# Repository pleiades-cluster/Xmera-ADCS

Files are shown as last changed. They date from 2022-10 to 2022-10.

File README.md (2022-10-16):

# Xmera-ADCS
The Official ADCS Design on PROVES Xmera
# ADCS_V1
This was the first version of the ADCS board developed by Rachel Sarmiento and Nicole Maggard. This board was uploaded on 10/12/2022 and is the most relevant and up to date version. This board utilizes a raspberry pi zero for calculations and control. This board includes an embedded Magnetorquer in the inner layers. Parts utilized on V1 include: STSPIN250 (Motor Drivers), PCA9548A (I2C Multiplexer), LIS331LH (6D Orientation IMUs), and LIS3MDL (Magnetometers).

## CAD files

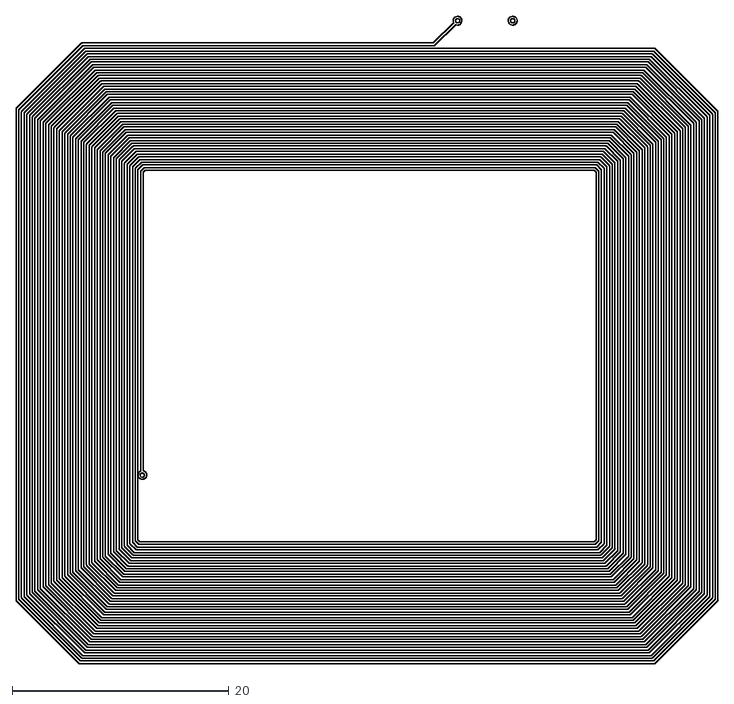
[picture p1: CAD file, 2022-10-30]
ADCS_V1/V0 Coil-In2_Cu.dxf
64.8 x 59.7

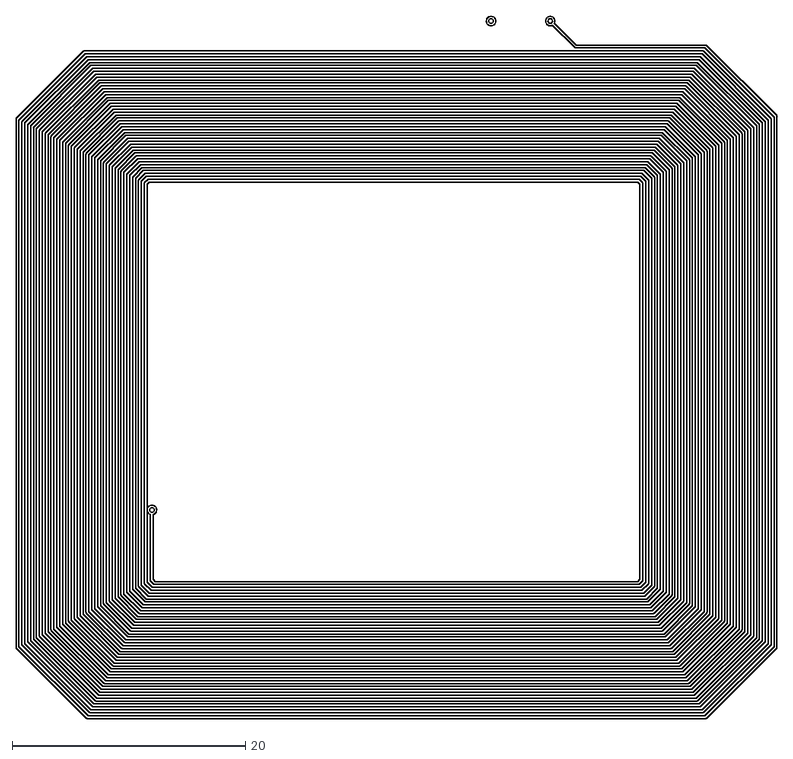
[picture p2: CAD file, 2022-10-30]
ADCS_V1/V0 Coil-In1_Cu.dxf
65.3 x 60.2

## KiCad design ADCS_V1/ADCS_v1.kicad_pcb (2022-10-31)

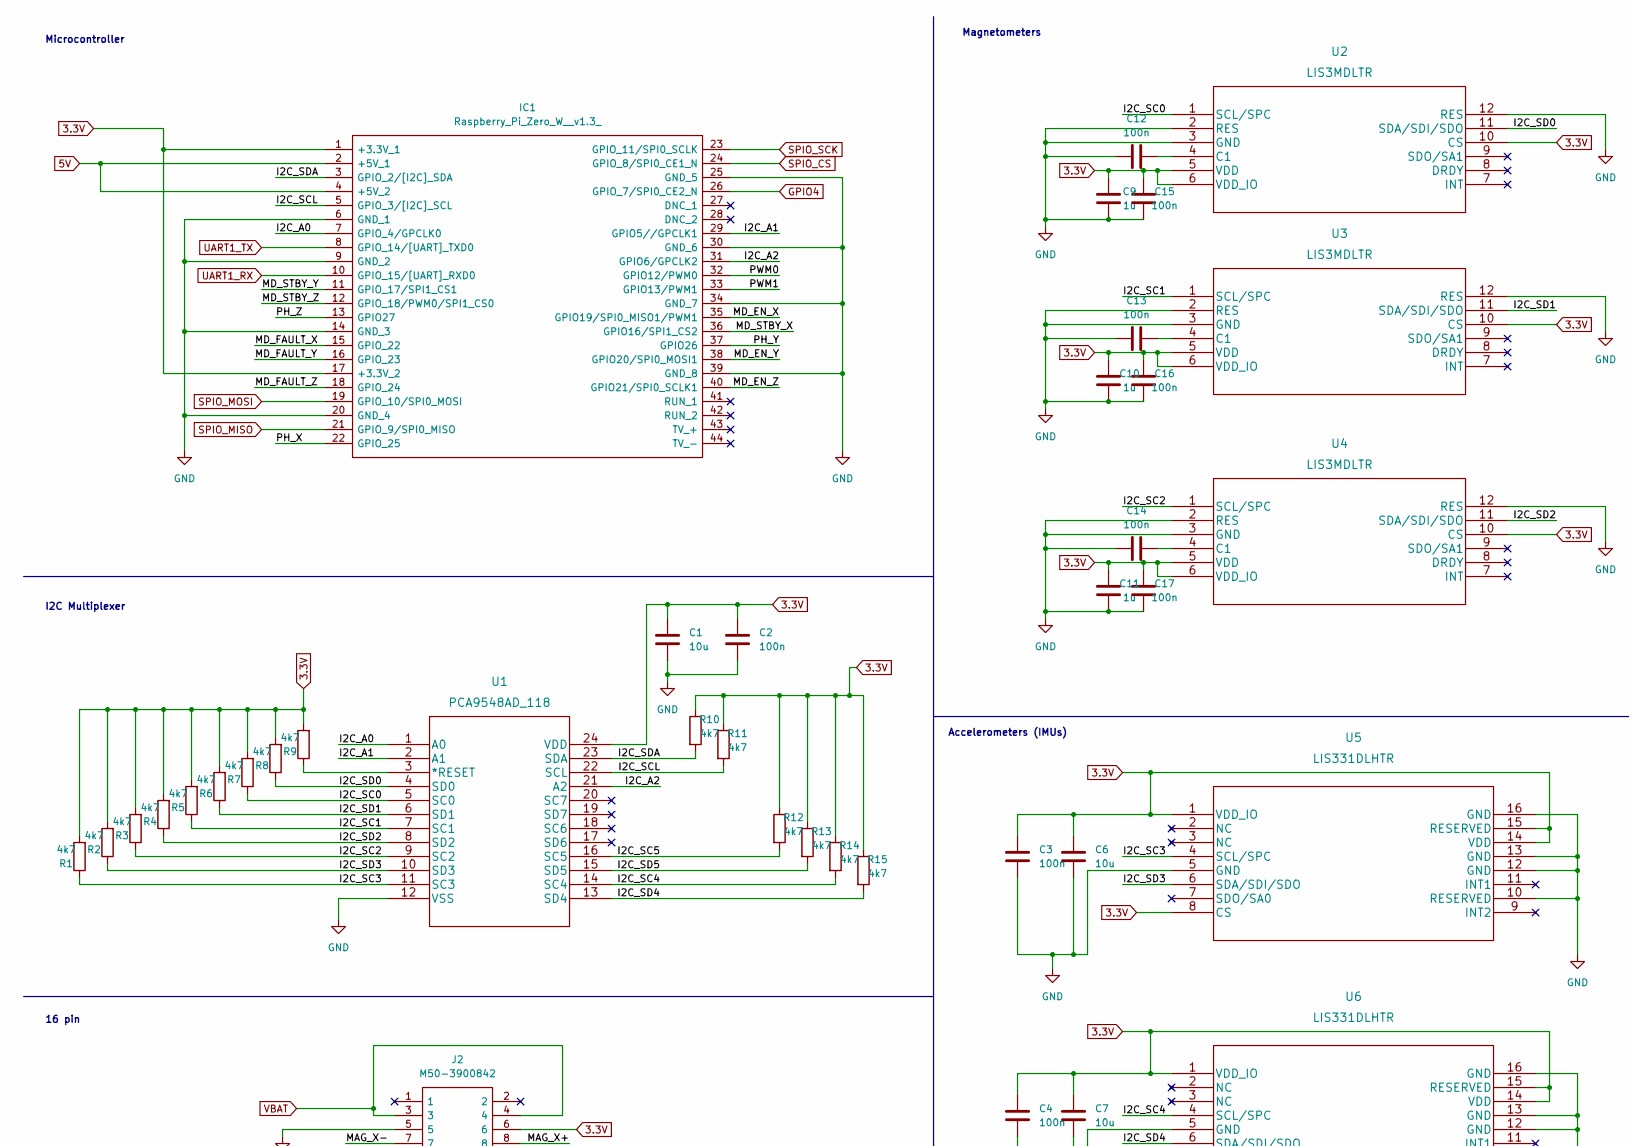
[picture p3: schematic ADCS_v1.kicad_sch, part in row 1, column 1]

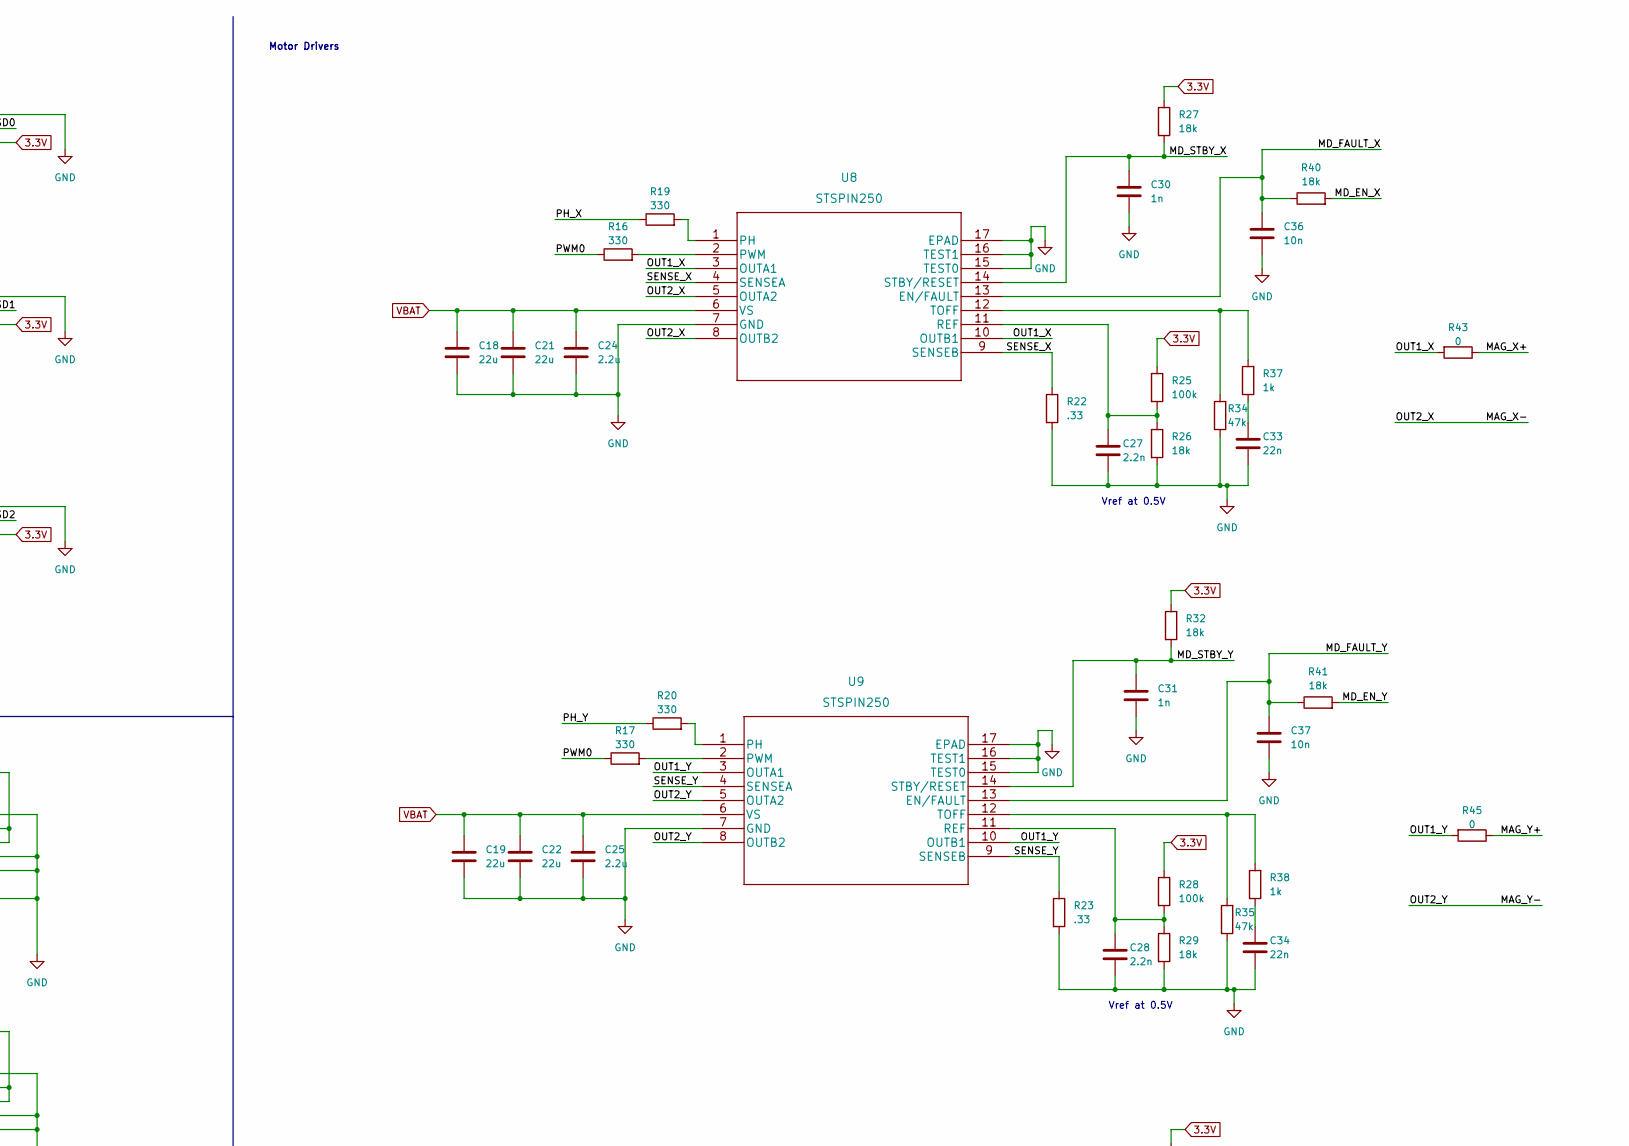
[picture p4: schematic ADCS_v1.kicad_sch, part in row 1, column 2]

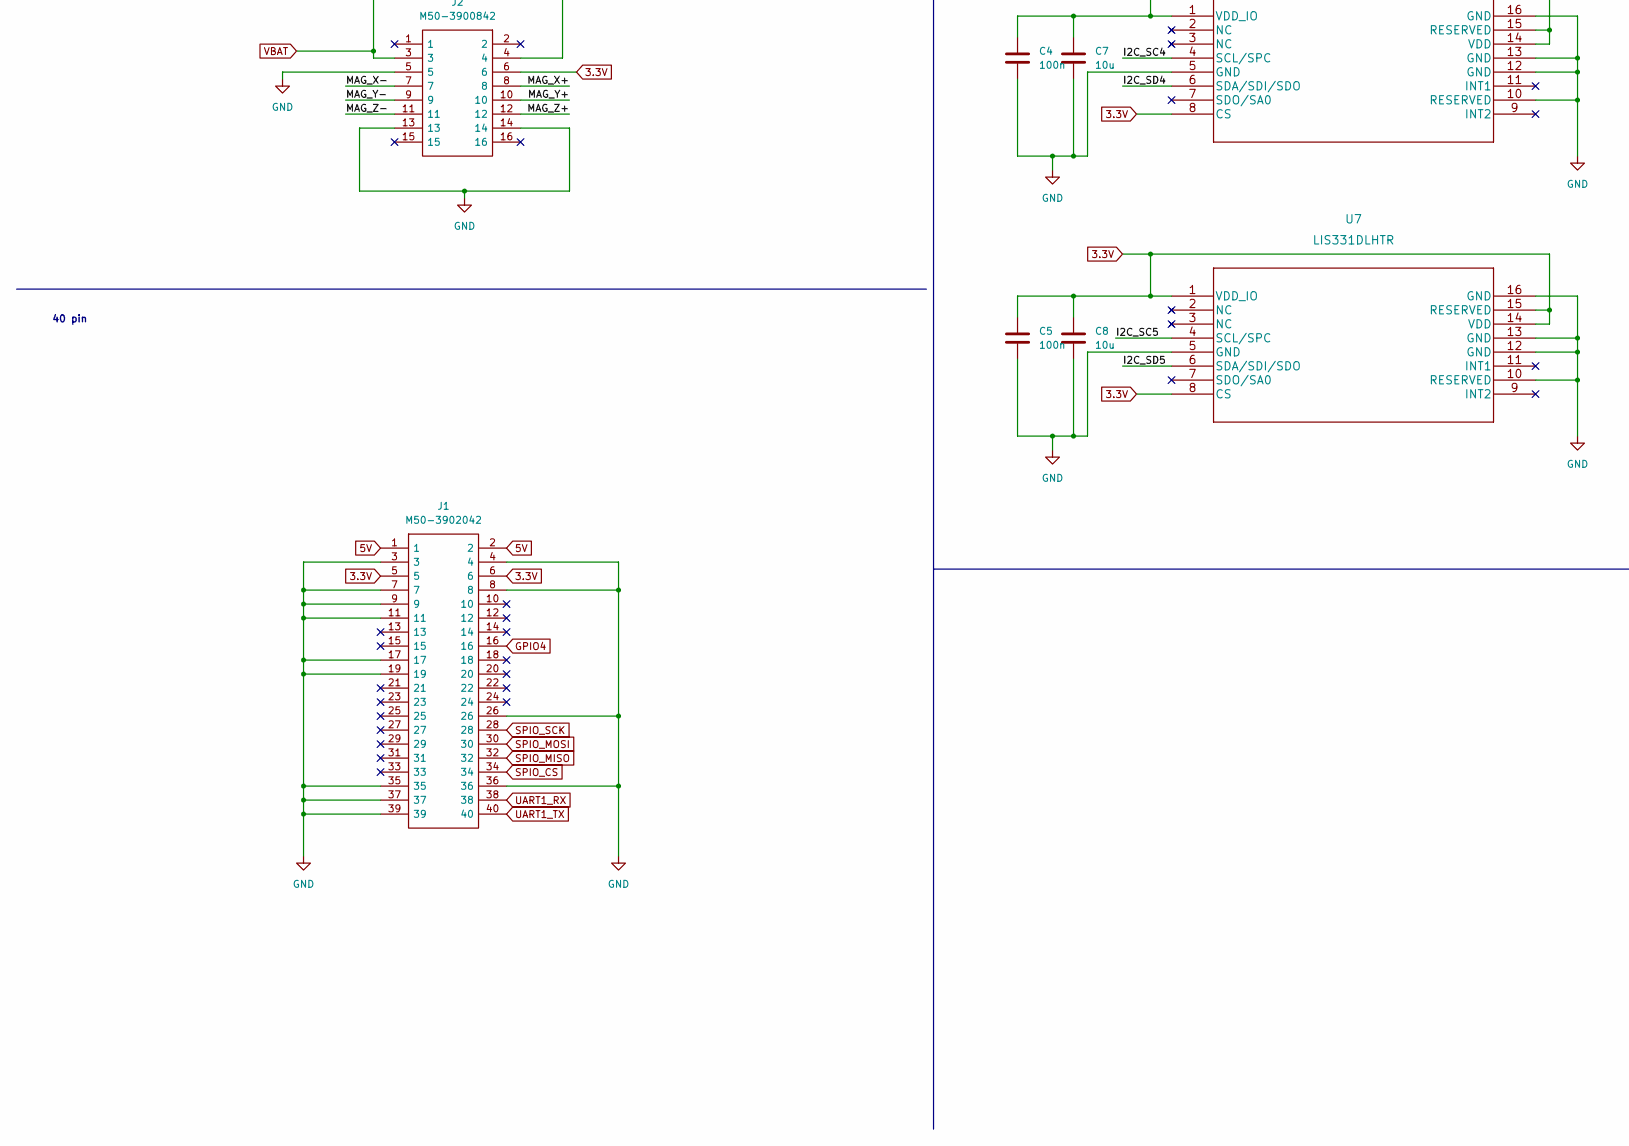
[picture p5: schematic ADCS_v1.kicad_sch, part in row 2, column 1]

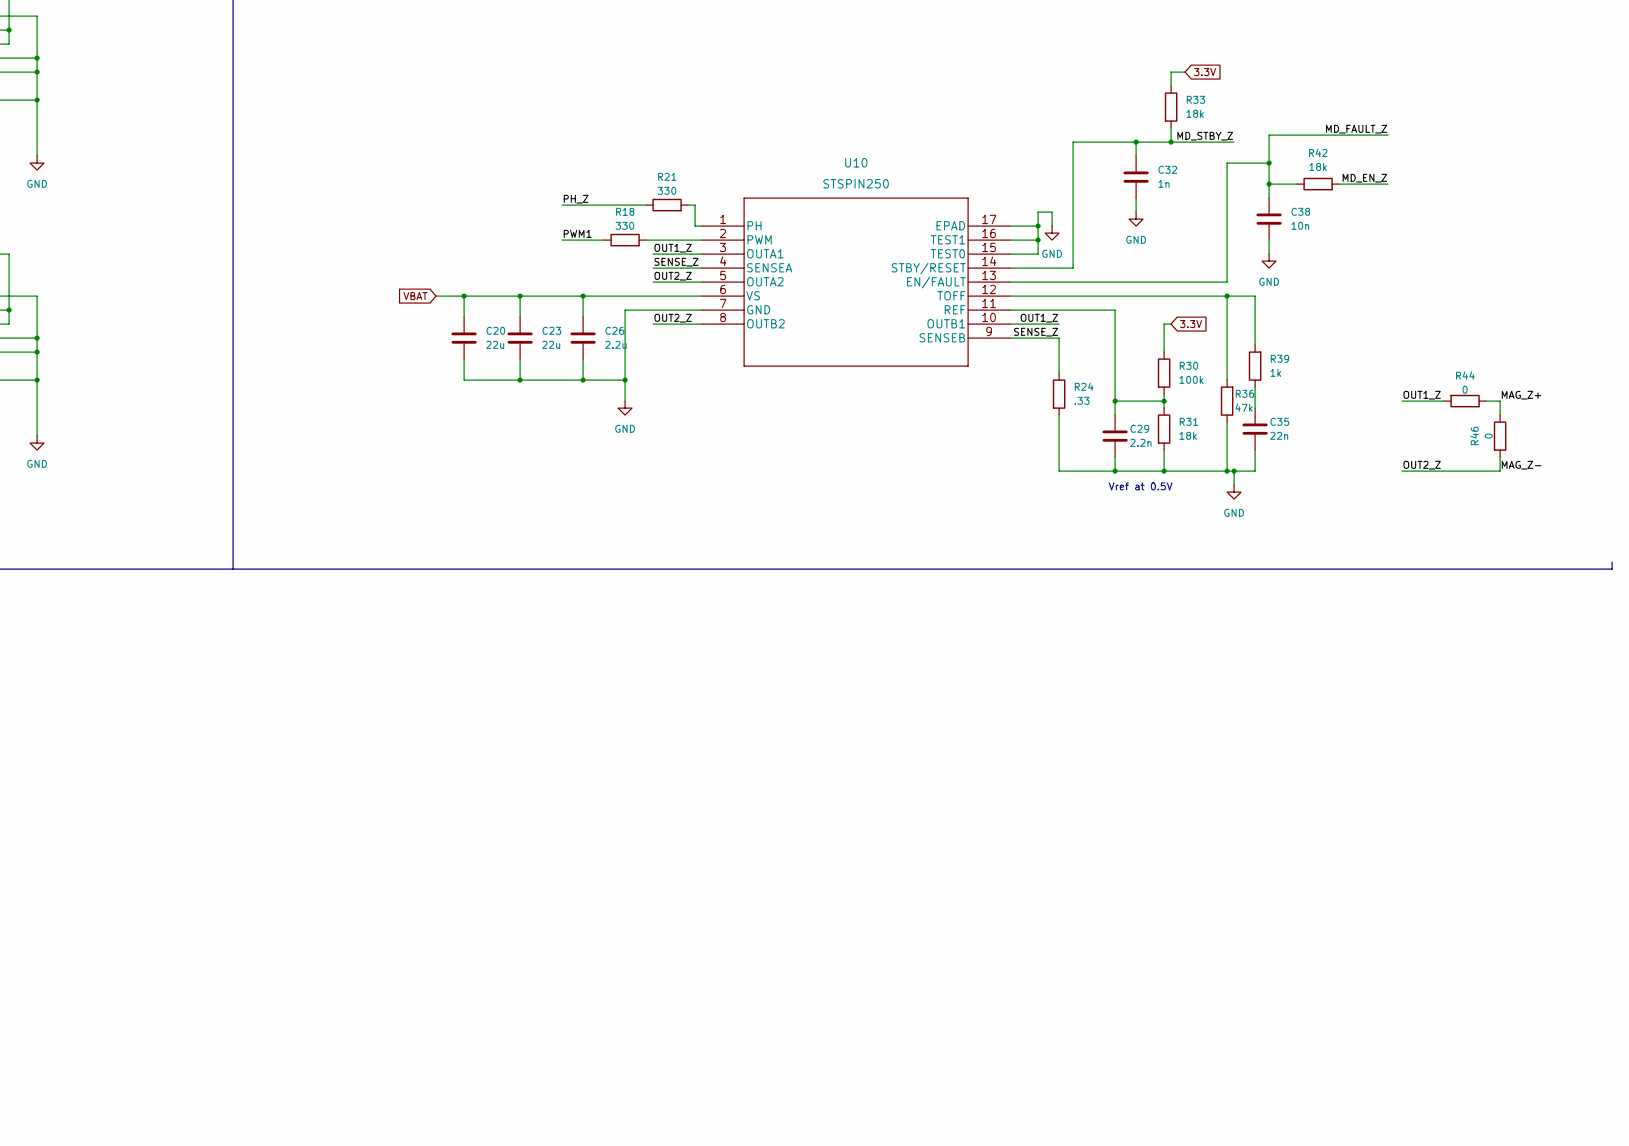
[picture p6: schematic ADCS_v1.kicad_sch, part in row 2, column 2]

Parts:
C1, C6, C7, C8: 10u; C_0603_1608Metric
C2, C3, C4, C5, C12, C13, C14, C15, C16, C17: 100n; C_0402_1005Metric
C9, C10, C11: 1u; C_0402_1005Metric
C18, C19, C20, C21, C22, C23: 22u; C_0805_2012Metric
C24, C25, C26: 2.2u; C_0603_1608Metric
C27, C28, C29: 2.2n; C_0402_1005Metric
C30, C31, C32: 1n; C_0402_1005Metric
C33, C34, C35: 22n; C_0402_1005Metric
C36, C37, C38: 10n; C_0402_1005Metric
IC1: Raspberry_Pi_Zero_W__v1.3_; RASPBERRYPIZEROWV13; Manufacturer_Part_Number Raspberry Pi Zero W (v1.3)
J1: M50-3902042; Mouser Part Number 855-M50-3902042
J2: M50-3900842; Mouser Part Number 855-M50-3900842
R1, R2, R3, R4, R5, R6, R7, R8, R9, R10, R11, R12, R13, R14, R15: 4k7; R_0402_1005Metric
R16, R17, R18, R19, R20, R21: 330; R_0402_1005Metric
R22, R23, R24: .33; R_0402_1005Metric
R25, R28, R30: 100k; R_0805_2012Metric
R26, R27, R29, R31, R32, R33, R40, R41, R42: 18k; R_0603_1608Metric
R34, R35, R36: 47k; R_0805_2012Metric
R37, R38, R39: 1k; R_0402_1005Metric
R43, R44, R45, R46: 0; R_0402_1005Metric
U1: PCA9548AD_118; SO24_SOT137-1_NXP
U2, U3, U4: LIS3MDLTR; LGA-12_2X2X1_STM
U5, U6, U7: LIS331DLHTR; LGA-16_3x3x1mm_STM
U8, U9, U10: STSPIN250; VFQFPN16_STSPIN_STM

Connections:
3.3V: C1.1, C2.1, C3.1, C4.1, C5.1, C6.1, C7.1, C8.1, C9.2, C10.2, C11.2, C15.2, C16.2, C17.2, IC1.1 (+3.3V_1), IC1.17 (+3.3V_2), J1.5, J1.6, J2.6, R1.2, R2.2, R3.2, R4.2, R5.2, R6.2, R7.2, R8.2, R9.2, R10.1, R11.1, R12.1, R13.1, R14.1, R15.1, R25.1, R27.1, R28.1, R30.1, R32.1, R33.1, U1.24 (VDD), U2.5 (VDD), U2.6 (VDD_IO), U2.10 (CS), U3.5 (VDD), U3.6 (VDD_IO), U3.10 (CS), U4.5 (VDD), U4.6 (VDD_IO), U4.10 (CS), U5.1 (VDD_IO), U5.8 (CS), U5.14 (VDD), U5.15 (RESERVED), U6.1 (VDD_IO), U6.8 (CS), U6.14 (VDD), U6.15 (RESERVED), U7.1 (VDD_IO), U7.8 (CS), U7.14 (VDD), U7.15 (RESERVED); also elsewhere on the board
5V: IC1.2 (+5V_1), IC1.4 (+5V_2), J1.1, J1.2
/I2C_A0: IC1.7 (GPIO_4/GPCLK0), U1.1 (A0)
/I2C_A1: IC1.29 (GPIO5//GPCLK1), U1.2 (A1)
/I2C_A2: IC1.31 (GPIO6/GPCLK2), U1.21 (A2); also elsewhere on the board
/I2C_SC0: R7.1, U1.5 (SC0), U2.1 (SCL/SPC)
/I2C_SC1: R5.1, U1.7 (SC1), U3.1 (SCL/SPC)
/I2C_SC2: R3.1, U1.9 (SC2), U4.1 (SCL/SPC)
/I2C_SC3: R1.1, U1.11 (SC3), U5.4 (SCL/SPC)
/I2C_SC4: R14.2, U1.14 (SC4), U6.4 (SCL/SPC)
/I2C_SC5: R12.2, U1.16 (SC5), U7.4 (SCL/SPC)
/I2C_SCL: IC1.5 (GPIO_3/[I2C]_SCL), R11.2, U1.22 (SCL)
/I2C_SD0: R8.1, U1.4 (SD0), U2.11 (SDA/SDI/SDO)
/I2C_SD1: R6.1, U1.6 (SD1), U3.11 (SDA/SDI/SDO)
/I2C_SD2: R4.1, U1.8 (SD2), U4.11 (SDA/SDI/SDO)
/I2C_SD3: R2.1, U1.10 (SD3), U5.6 (SDA/SDI/SDO)
/I2C_SD4: R15.2, U1.13 (SD4), U6.6 (SDA/SDI/SDO)
/I2C_SD5: R13.2, U1.15 (SD5), U7.6 (SDA/SDI/SDO)
/I2C_SDA: IC1.3 (GPIO_2/[I2C]_SDA), R10.2, U1.23 (SDA)
/MAG_X+: J2.8, R43.1
/MAG_X-: J2.7, U8.5 (OUTA2), U8.8 (OUTB2)
/MAG_Y+: J2.10, R45.1
/MAG_Y-: J2.9, U9.5 (OUTA2), U9.8 (OUTB2)
/MAG_Z+: J2.12, R44.1, R46.1
/MAG_Z-: J2.11, R46.2, U10.5 (OUTA2), U10.8 (OUTB2)
/MD_EN_X: IC1.35 (GPIO19/SPI0_MISO1/PWM1), R40.2
/MD_EN_Y: IC1.38 (GPIO20/SPI0_MOSI1), R41.2
/MD_EN_Z: IC1.40 (GPIO21/SPI0_SCLK1), R42.2
/MD_FAULT_X: C36.1, IC1.15 (GPIO_22), R40.1, U8.13 (EN/FAULT)
/MD_FAULT_Y: C37.1, IC1.16 (GPIO_23), R41.1, U9.13 (EN/FAULT)
/MD_FAULT_Z: C38.1, IC1.18 (GPIO_24), R42.1, U10.13 (EN/FAULT)
/MD_STBY_X: C30.1, IC1.36 (GPIO16/SPI1_CS2), R27.2, U8.14 (STBY/RESET)
/MD_STBY_Y: C31.1, IC1.11 (GPIO_17/SPI1_CS1), R32.2, U9.14 (STBY/RESET)
/MD_STBY_Z: C32.1, IC1.12 (GPIO_18/PWM0/SPI1_CS0), R33.2, U10.14 (STBY/RESET)
/OUT1_X: R43.2, U8.3 (OUTA1), U8.10 (OUTB1)
/OUT1_Y: R45.2, U9.3 (OUTA1), U9.10 (OUTB1)
/OUT1_Z: R44.2, U10.3 (OUTA1), U10.10 (OUTB1)
/PH_X: IC1.22 (GPIO_25), R19.1
/PH_Y: IC1.37 (GPIO26), R20.1
/PH_Z: IC1.13 (GPIO27), R21.1
/PWM0: IC1.32 (GPIO12/PWM0), R16.1, R17.1
/PWM1: IC1.33 (GPIO13/PWM1), R18.1
/SENSE_X: R22.1, U8.4 (SENSEA), U8.9 (SENSEB)
/SENSE_Y: R23.1, U9.4 (SENSEA), U9.9 (SENSEB)
/SENSE_Z: R24.1, U10.4 (SENSEA), U10.9 (SENSEB)
GND: C1.2, C2.2, C3.2, C4.2, C5.2, C6.2, C7.2, C8.2, C9.1, C10.1, C11.1, C12.1, C13.1, C14.1, C15.1, C16.1, C17.1, C18.2, C19.2, C20.2, C21.2, C22.2, C23.2, C24.2, C25.2, C26.2, C27.2, C28.2, C29.2, C30.2, C31.2, C32.2, C33.2, C34.2, C35.2, C36.2, C37.2, C38.2, IC1.6 (GND_1), IC1.9 (GND_2), IC1.14 (GND_3), IC1.20 (GND_4), IC1.25 (GND_5), IC1.30 (GND_6), IC1.34 (GND_7), IC1.39 (GND_8), J1.3, J1.4, J1.7, J1.8, J1.9, J1.11, J1.17, J1.19, J1.26, J1.35, J1.36, J1.37, J1.39, J2.5, J2.13, J2.14, R22.2, R23.2, R24.2, R26.2, R29.2, R31.2, R34.1, R35.1, R36.1, U1.12 (VSS), U2.2 (RES), U2.3 (GND), U2.12 (RES), U3.2 (RES), U3.3 (GND), U3.12 (RES), U4.2 (RES), U4.3 (GND), U4.12 (RES), U5.5 (GND), U5.10 (RESERVED), U5.12 (GND), U5.13 (GND), U5.16 (GND), U6.5 (GND), U6.10 (RESERVED), U6.12 (GND), U6.13 (GND), U6.16 (GND), U7.5 (GND), U7.10 (RESERVED), U7.12 (GND), U7.13 (GND), U7.16 (GND), U8.7 (GND), U8.15 (TEST0), U8.16 (TEST1), U8.17 (EPAD), U9.7 (GND), U9.15 (TEST0), U9.16 (TEST1), U9.17 (EPAD), U10.7 (GND), U10.15 (TEST0), U10.16 (TEST1), U10.17 (EPAD)
GPIO4: IC1.26 (GPIO_7/SPI0_CE2_N), J1.16
unnamed: C12.2, U2.4 (C1)
unnamed: C13.2, U3.4 (C1)
unnamed: C14.2, U4.4 (C1)
unnamed: C27.1, R25.2, R26.1, U8.11 (REF)
unnamed: C28.1, R28.2, R29.1, U9.11 (REF)
unnamed: C29.1, R30.2, R31.1, U10.11 (REF)
unnamed: C33.1, R37.1
unnamed: C34.1, R38.1
unnamed: C35.1, R39.1
unnamed: R9.1, U1.3 (*RESET)
unnamed: R16.2, U8.2 (PWM)
unnamed: R17.2, U9.2 (PWM)
unnamed: R18.2, U10.2 (PWM)
unnamed: R19.2, U8.1 (PH)
unnamed: R20.2, U9.1 (PH)
unnamed: R21.2, U10.1 (PH)
unnamed: R34.2, R37.2, U8.12 (TOFF)
unnamed: R35.2, R38.2, U9.12 (TOFF)
unnamed: R36.2, R39.2, U10.12 (TOFF)
SPIO_CS: IC1.24 (GPIO_8/SPI0_CE1_N), J1.34
SPIO_MISO: IC1.21 (GPIO_9/SPI0_MISO), J1.32
SPIO_MOSI: IC1.19 (GPIO_10/SPI0_MOSI), J1.30
SPIO_SCK: IC1.23 (GPIO_11/SPI0_SCLK), J1.28
UART1_RX: IC1.10 (GPIO_15/[UART]_RXD0), J1.38
UART1_TX: IC1.8 (GPIO_14/[UART]_TXD0), J1.40
VBAT: C18.1, C19.1, C20.1, C21.1, C22.1, C23.1, C24.1, C25.1, C26.1, J2.3, J2.4, U8.6 (VS), U9.6 (VS), U10.6 (VS)

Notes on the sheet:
Motor Drivers
Vref at 0.5V
16 pin
Magnetometers
40 pin
I2C Multiplexer
Microcontroller
Accelerometers (IMUs)

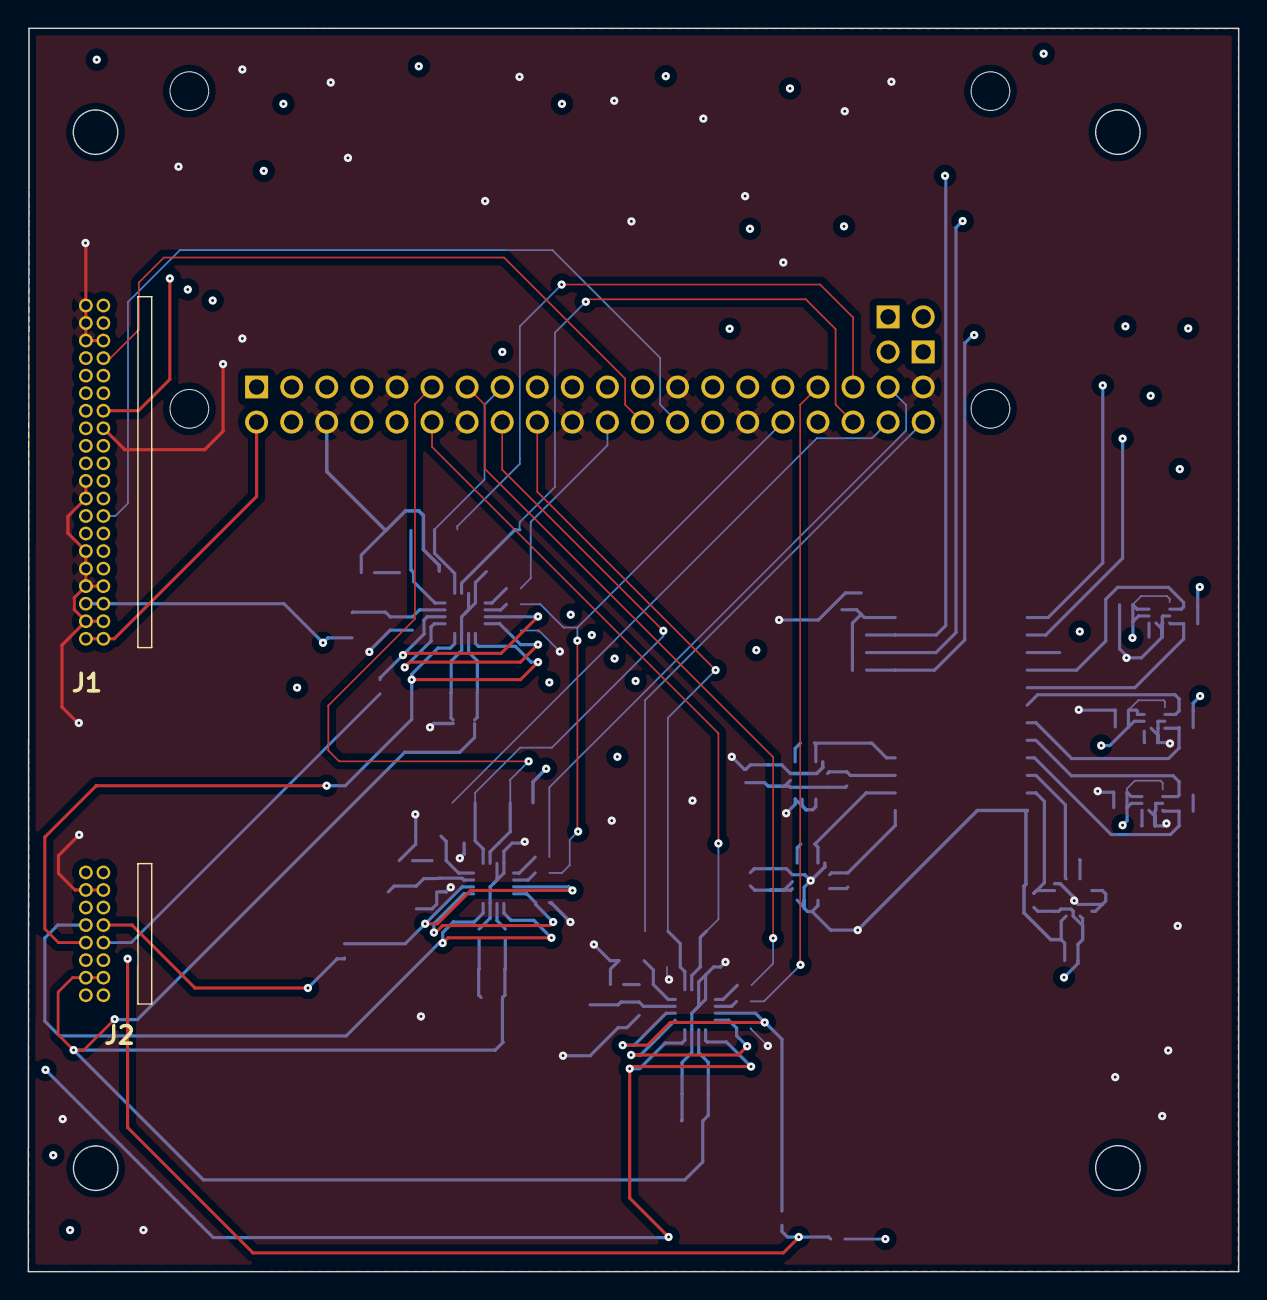
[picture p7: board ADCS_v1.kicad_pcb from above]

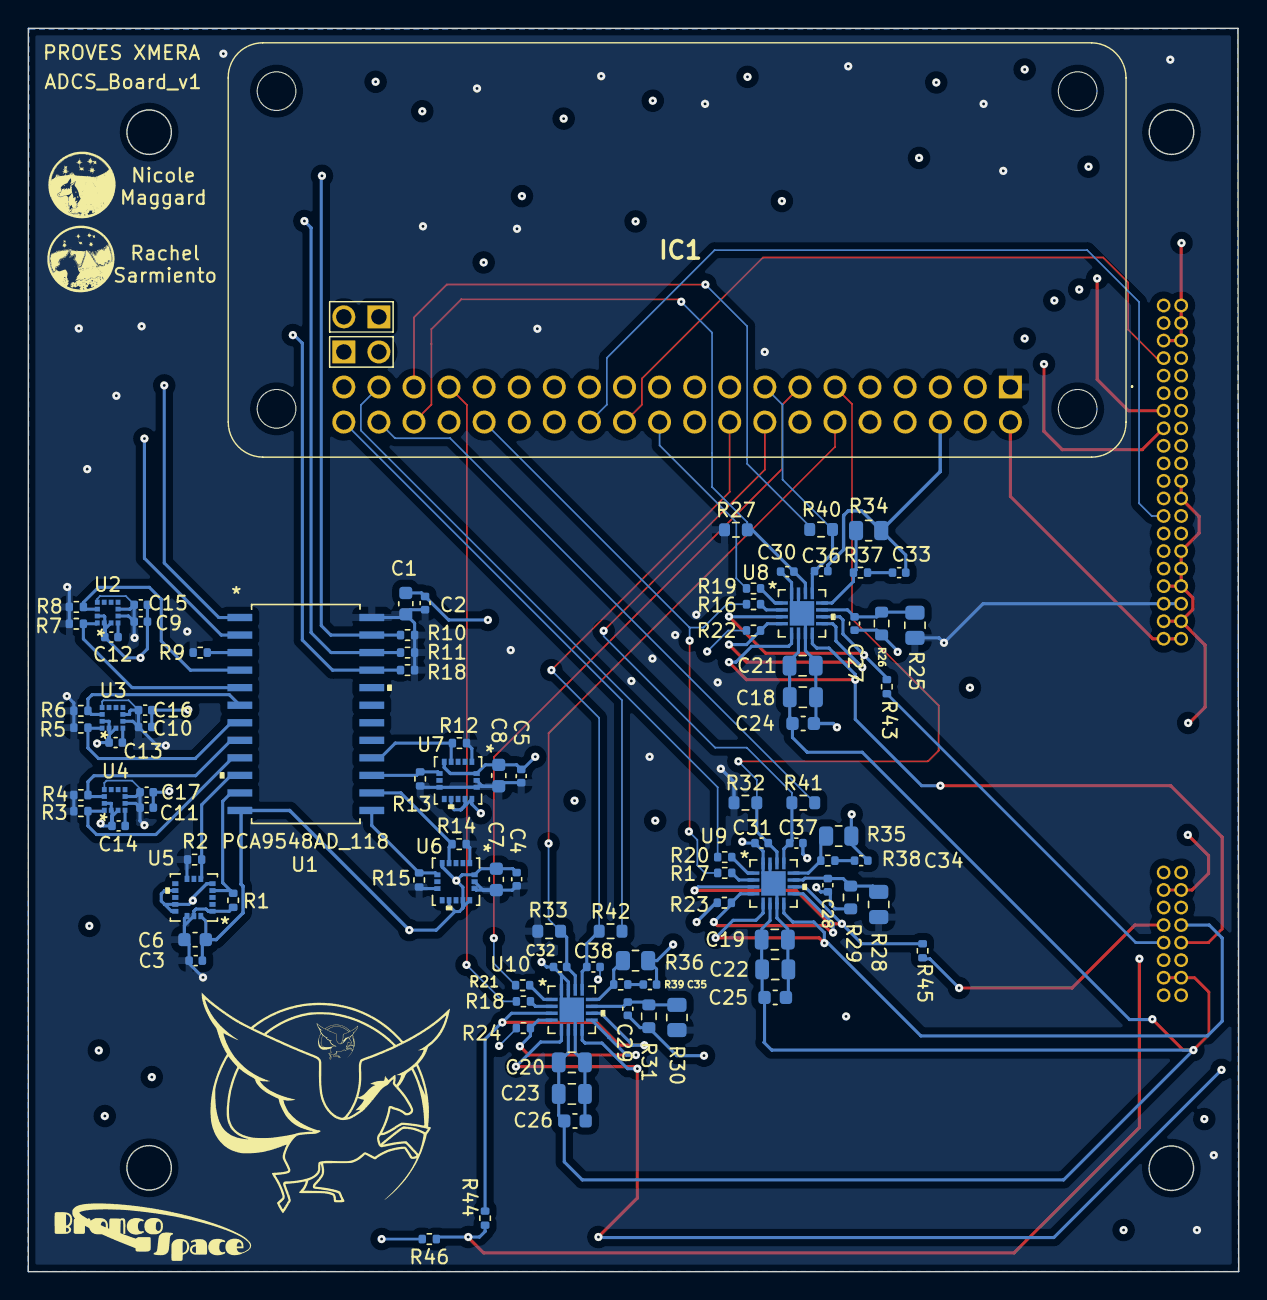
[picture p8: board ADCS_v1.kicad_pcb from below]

Board: 4 copper layers, 87.6 x 90.0 mm, 98 parts (96 on the bottom side), 73 nets.

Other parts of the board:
R18#2: 4k7; R_0402_1005Metric

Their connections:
3.3V: R18#2.1; also elsewhere on the board
/I2C_A2: R18#2.2; also elsewhere on the board

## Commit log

2022-10-12 The first version of ADCS
    [ADCS_v1.kicad_pcb, ADCS_v1.kicad_sch]
2022-10-16 40 pin and 16 pin def update
    [ADCS_v1.kicad_pcb, ADCS_v1.kicad_sch]
2022-10-30 changed connector positions
    [ADCS_v1.kicad_pcb, ADCS_v1.kicad_sch, V0 Coil-In1_Cu.dxf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]
2022-10-31 updated connectors and 3dmodels
    [ADCS_v1.kicad_pcb]

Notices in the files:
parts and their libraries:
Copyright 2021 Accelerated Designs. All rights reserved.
